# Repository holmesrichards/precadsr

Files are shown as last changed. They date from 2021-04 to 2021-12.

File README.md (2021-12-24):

# Kassutronics Precision ADSR with retriggering and looping modifications

This is an ADSR envelope generator synth module. Layout and panel are Kosmo format. 

The main part of the design is from [Kassutronics](https://kassu2000.blogspot.com/2015/05/precision-adsr.html), who in turn based it on the YuSynth [ADSR (version 2)](http://yusynth.net/Modular/EN/ADSR/index_new.html), which is similar to René Schmitz's [Fastest Envelope In the West](https://www.schmitzbits.de/adsr.html). The latter two, like some other envelope generators, have the problem that the voltage releases very slowly after reaching about 700 mV, taking several seconds or longer to drop below 100 mV. Kassutronics fixed this by replacing the decay and release diodes with precision rectifiers (op amp with diode in the feedback loop). Another modification was a clever way of combining the LED indicator with the inverted envelope output using a single op amp.

The present design adds the following features:

* Two switch selectable capacitors for slower and faster time scales (restoring a feature of the YuSynth ADSR, though without the two resistors in the attack path).
* Capacitors can be socketed for experimentation, soldered, or socketed at first and soldered later.
* Retriggering input, allowing additional attack/decay peaks on top of the sustain (inspired by but simplified from Benjamin AM's [design](https://electro-music.com/forum/post-372492.html#372492)).
* Looping mode, allowing attack-decay envelopes to repeat as long as a gate is present, or, if nothing is plugged into the gate input, indefinitely. This can be used as a sequence of envelopes or as a kind of odd LFO.

## Current draw
12 mA +12 V, 10 mA -12 V

## Photos

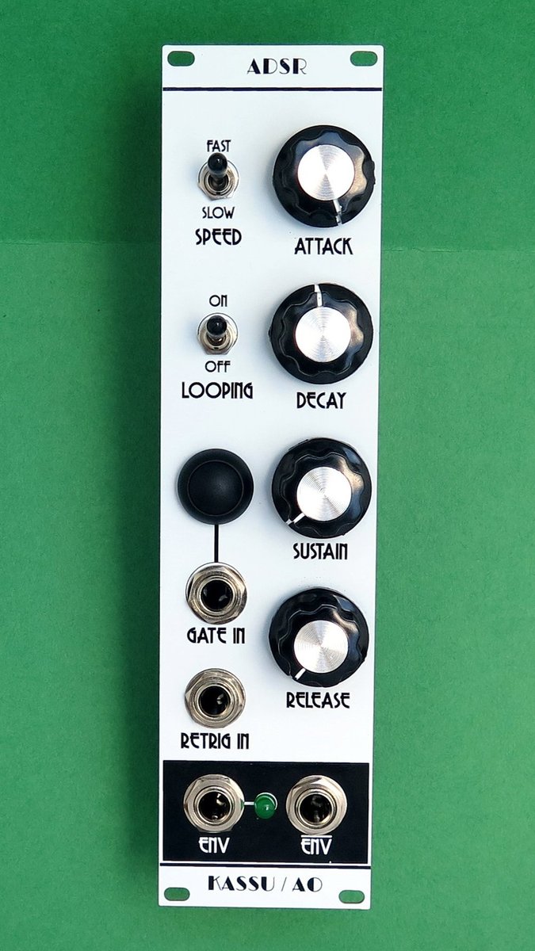
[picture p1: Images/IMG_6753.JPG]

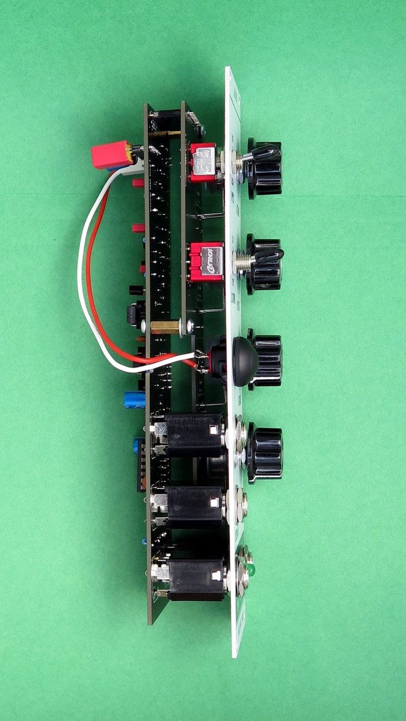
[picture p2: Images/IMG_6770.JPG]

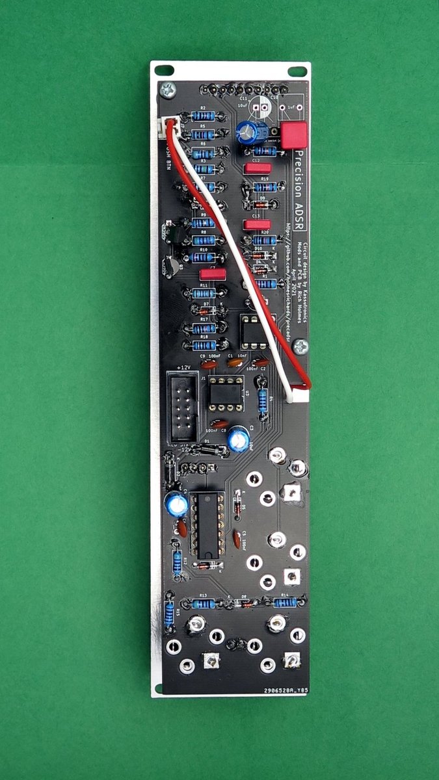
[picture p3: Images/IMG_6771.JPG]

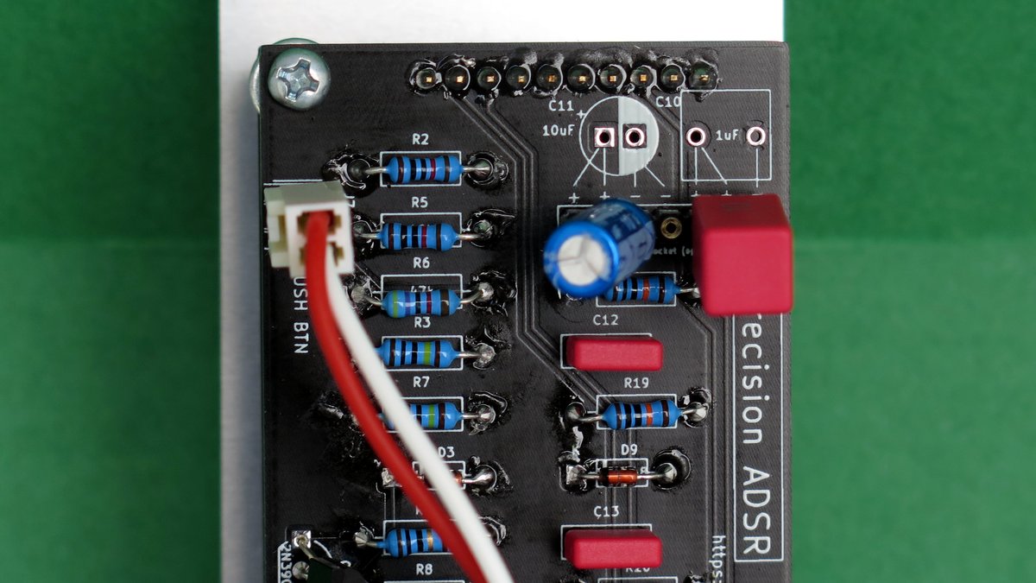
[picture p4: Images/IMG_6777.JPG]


## Documentation:

* [Schematic](Docs/precadsr.pdf)
* PCB layout: [front](Docs/precadsr_layout_front.pdf), [back](Docs/precadsr_layout_back.pdf)
* [BOM](Docs/precadsr_bom.md)
* [Build notes](Docs/build.md)
* [How to use](Docs/use.md)

## GitHub repository

* [https://github.com/holmesrichards/precadsr](https://github.com/holmesrichards/precadsr)

## Submodules

This repo uses submodules aoKicad and Kosmo_panel, which provide needed libaries for KiCad. To clone:

```
git clone git@github.com:holmesrichards/precadsr.git
git submodule init
git submodule update
```

Alternatively do

```
git clone --recurse-submodules git@github.com:holmesrichards/precadsr.git
```

Or if you download the repository as a zip file, you must also click on the "aoKicad" and "Kosmo\_panel" links on the GitHub page (they'll have "@ something" after them) and download them as separate zip files which you can unzip into the aoKicad and Kosmo\_panel directories.

If desired, copy the files from aoKicad and Kosmo\_panel to wherever you prefer (your KiCad user library directory, for instance, if you have one). Then in KiCad, add symbol libraries 

```
aoKicad/ao_symbols
Kosmo_panel/Kosmo
```
and footprint libraries 
```
aoKicad/ao_tht
Kosmo_panel/Kosmo_panel.
```

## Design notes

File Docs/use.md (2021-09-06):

# Using the Precision ADSR with retriggering and looping

## Gated ADSR operation

It's just like pretty much any ADSR envelope generator. Put a gate into the Gate In jack (or generate a gate manually using the push button). The start (rising edge) of the gate will initiate the attack, followed by the decay to the sustain level after maximum amplitude is reached (about 8 V). The end (falling edge) of the gate will initiate the release to 0 V. Attack, Decay, and Release times, and Sustain level, are set using the knobs. The Speed switch allows choosing faster or slower time ranges for the Attack, Decay, and Release times.

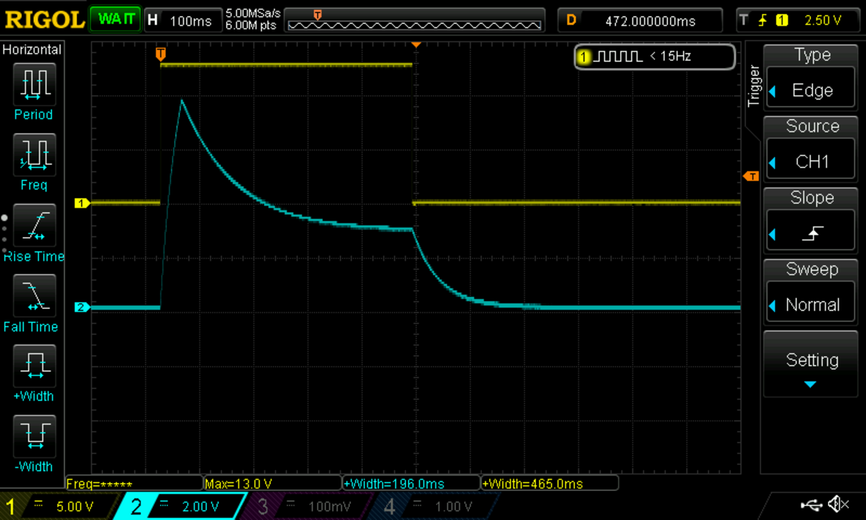
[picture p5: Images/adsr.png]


## Inverted output

Whatever appears on the Env output, its negative will appear on the ~Env output. You can use this, for instance, to duck a VCA level using a gate.

## Retriggering

It can be useful to have a new Attack/Decay for new notes without a release to 0 V before them. To do this send a gate to the Gate In (or push the button) and triggers to Retrig In. As usual the gate will initiate an Attack, Decay, Sustain, and Release. However, pulses on the Retrig In jack during the Decay/Sustain phase will cause new Attacks and Decays to occur.

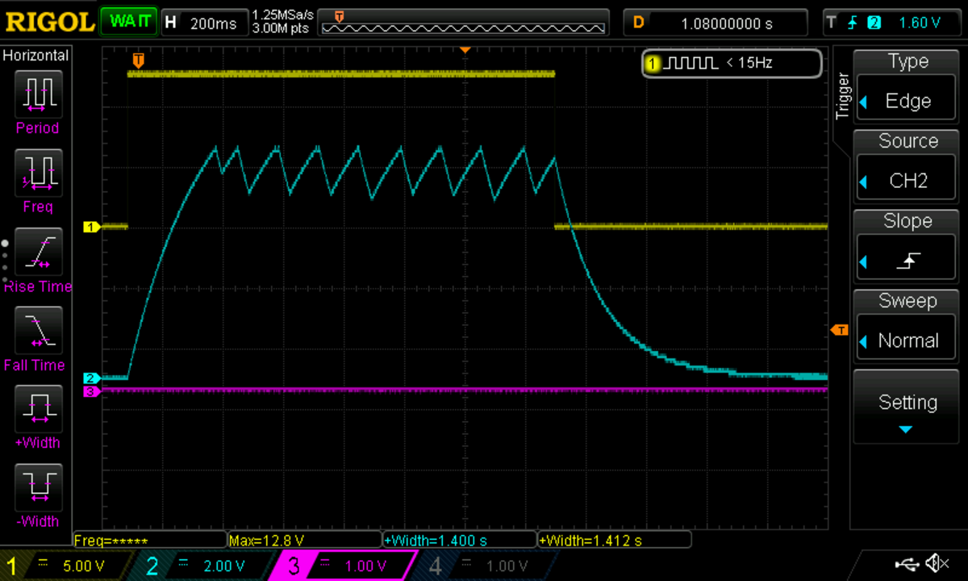
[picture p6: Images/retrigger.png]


## Looping

With the Looping switch in the On position, a gate on the Gate In (or pushing the button) will initiate an Attack and Decay to 0 V. The Sustain level and Release times are ignored. When the output gets close to 0 V it will automatically trigger a new Attack and Decay. The Attacks and Decays will repeat as long as the gate is on. When the gate goes off the looping ends.

If nothing is plugged in on the Gate In jack and Looping is turned on, Attacks and Decays will repeat continuously.

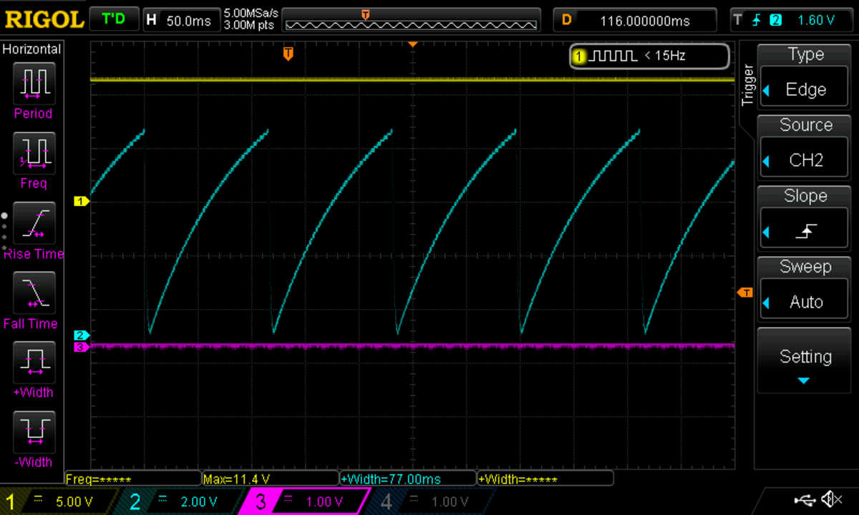
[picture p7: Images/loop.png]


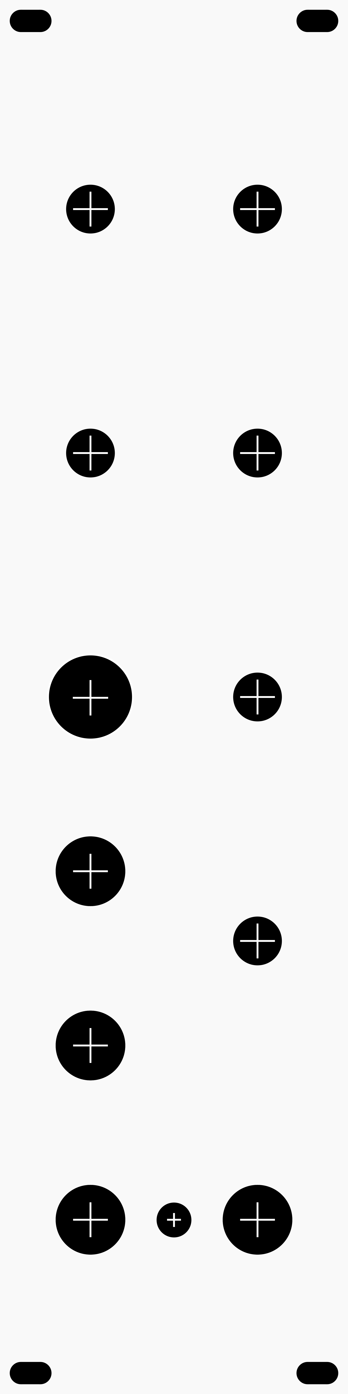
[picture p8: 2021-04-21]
Images/precadsr-panel-holes.png

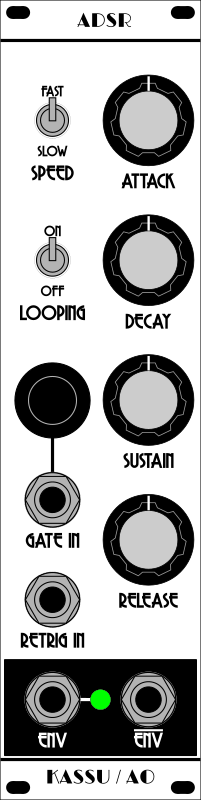
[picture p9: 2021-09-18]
Images/precadsr-panel.png

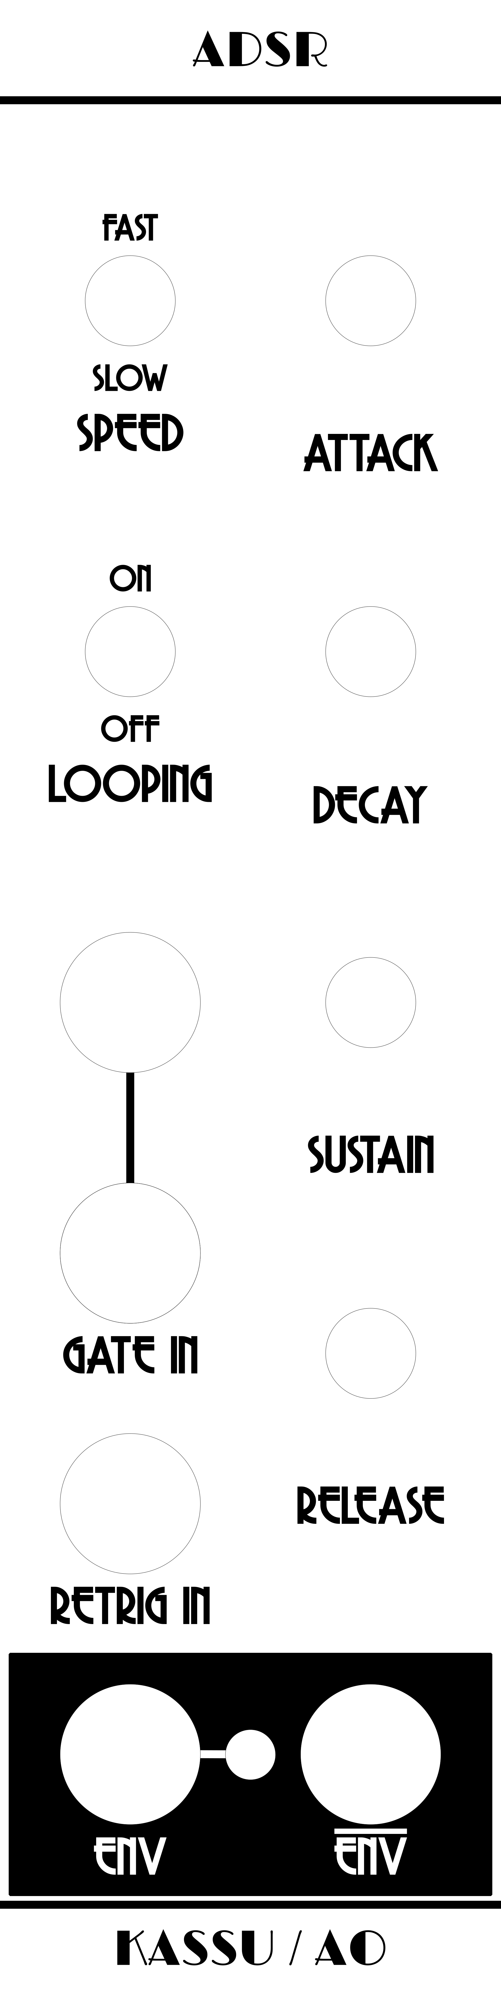
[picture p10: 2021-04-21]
Images/precadsr-panel-art.png

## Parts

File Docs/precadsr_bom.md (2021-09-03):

# precadsr.sch BOM

Sat 28 Aug 2021 07:18:14 PM EDT

Generated from schematic by Eeschema 5.1.10-88a1d61d58~90~ubuntu20.04.1

**Component Count:** 76

| Refs | Qty | Component | Description | Manufacturer | Part | Vendor | SKU |
| ----- | --- | ---- | --- | ---- | ---- | ---- | ---- |
| C1 | 1 | 10nF | Ceramic capacitor |  |  | Tayda | A-962 |
| C2, C5, C6, C8, C9 | 5 | 100nF | Ceramic capacitor |  |  | Tayda | A-553 |
| C3, C4, C11 | 3 | 10uF | Electrolytic capacitor |  |  | Tayda | A-4349 |
| C7, C12 | 2 | 1nF | Film capacitor |  |  | Tayda | A-1531 or A-557 |
| C10 | 1 | 1uF | Film capacitor |  |  | Tayda | A-4755 |
| C13 | 1 | 10nF | Film capacitor |  |  | Tayda | A-559 |
| D1, D2 | 2 | 1N5817 | Schottky Barrier Rectifier Diode, DO-41 |  |  | Tayda | A-159 |
| D3, D4, D5, D6, D7, D8, D9, D10 | 8 | 1N4148 | Standard switching diode, DO-35 |  |  | Tayda | A-157 |
| J1 | 1 | Synth_power_2x5 | Pin header 2.54 mm 2x5 |  |  | Tayda | A-2939 |
| J2 | 1 | AudioJack2_SwitchT | Audio Jack, 2 Poles (Mono / TS), Switched T Pole (Normalling) |  |  | Tayda | A-1121 |
| J3, J4, J5 | 3 | AudioJack2 | Audio Jack, 2 Poles (Mono / TS) |  |  | Tayda | A-1121 |
| J6 | 1 | Conn_01x07 | \*(optional) SIP socket, 2.54 mm, 1x7 |  |  | Tayda | A-1605 |
| J7 | 1 | 2_pin_Molex_header | KK254 Molex header |  |  | Tayda | A-804 |
| J8 | 1 | Conn_01x10 | Pin socket, 2.54 mm, 1x10 |  |  |  |  |
| J9 | 1 | Conn_01x04 | Pin socket, 2.54 mm, 1x4 |  |  |  |  |
| J10 | 1 | Conn_01x10 | Pin header, 2.54 mm, 1x10 |  |  |  |  |
| J11 | 1 | Conn_01x04 | Pin header, 2.54 mm, 1x4 |  |  |  |  |
| J12 | 1 | 2_pin_Molex_connector | KK254 Molex connector |  |  | Tayda | A-826 |
| L1 | 1 | LED | Light emitting diode, 5 mm |  |  |  |  |
| Q1, Q2, Q3 | 3 | 2N3904 | Small Signal NPN Transistor, TO-92 |  |  | Tayda | A-111 |
| R1, R10, R11 | 3 | 22k | Resistor |  |  |  |  |
| R2, R5 | 2 | 10k | Resistor |  |  |  |  |
| R3, R7 | 2 | 1M | Resistor |  |  |  |  |
| R4, R12, R13 | 3 | 4.7k | Resistor |  |  |  |  |
| R6, R8 | 2 | 47k | Resistor |  |  |  |  |
| R9 | 1 | 10R | Resistor |  |  |  |  |
| R14, R15, R18 | 3 | 1k | Resistor |  |  |  |  |
| R16, R17, R19, R20 | 4 | 100k | Resistor |  |  |  |  |
| R21, R22, R23 | 3 | 100R | Resistor |  |  |  |  |
| R24, R26, R28 | 3 | A1M | \*\*Potentiometer, 9 mm vertical board mount OR: |  |  | Tayda | A-1672 |
| R25, R27, R29 | 3 | A1M | \*\*Potentiometer, 16 mm vertical board mount |  | | Tayda | A-1157 or A-2425 |
| R30 | 1 | B10k | \*\*Potentiometer, 9 mm vertical board mount OR: |  |  | Tayda | A-1847 |
| R31 | 1 | B10k | \*\*Potentiometer, 16 mm vertical board mount |  |  | Tayda | A-1624 or A-2969 |
| S1 | 1 | SW_3PDT_x3 | 3PDT miniature toggle switch ON-ON |  |  | Tayda | A-1955 |
| S2 | 1 | SW_SPDT | SPDT miniature toggle switch ON-ON |  |  | Tayda | A-3186 |
| S3 | 1 | SW_Push | Push button switch OFF-(ON) | Dailywell | PAS6B3M1CESA3-5 or PAS6B3M1CESA2-5 | Tayda | A-3486 or A-3487\*\*\* |
| U1 | 1 | ICM7555xP | CMOS General Purpose Timer, 555 compatible, PDIP-8 |  |  |  |  |
| U2 | 1 | TL074 | Quad operational amplifier, DIP-14 |  |  | Tayda | A-1138 |
| U3 | 1 | TL071 | Operational amplifier, DIP-8 |  |  | Tayda | A-1135 |
| | 2 | | 8 pin DIP socket | | | Tayda | A-001 |
| | 1 | | 14 pin DIP socket | | | Tayda | A-004 |
| | 4 | | Knobs | | | |
| | | | Screws, nuts, and spacers (see [build notes](build.md))
| | 1 | Conn_01x02 | SIP socket, 2.54 mm, 1x2 (see [build notes](build.md)) |  |  | Tayda | A-1605 |

\* Fit SIP socket only if you want to socket the timing capacitors.
\*\* Use only four (4) potentiometers, either 9 mm or 16 mm vertical board mount. Only 16 mm have been tested and there could be mechanical difficulties using 9 mm. See [build notes](build.md).
\*\*\* A-3488 looks similar but is normally closed rather than normally open and will not work. Ask me how I know this. And by "ask me" I mean "shut up".

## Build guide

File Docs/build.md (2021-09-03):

# Precision ADSR build notes

The build is pretty straightforward except for mechanical assembly, and two other things:

## Erratum

C13 is marked on the first run PCBs as 1 nF. It should be 10 nF.

## Timing capacitors

C10 and C11 are the capacitors that determine the envelope shape in conjunction with the four pots. The "Speed" switch selects whether C10 ("fast") or C11 ("slow") is used. 1 µF for C10 and 10 µF for C11 is suggested but you can try other values, smaller ones for faster timings and larger ones for slower.

If you want to experiment, you can. J6 is an optional SIP socket (you could use a pin socket, but a SIP socket works better) for socketing the capacitors. There are 7 positions. As indicated by the lines on the silkscreen graphtics, the C11 + leg (if polarized) can go in either of the leftmost two positions, the C11 - leg in either of the next two, the C10 + leg in either of the next two, and the C10 - leg in the last one. This accommodates various possibilities for cap lead spacing. When and if you decide on a pair of capacitors you can solder them into the C10 and C11 footprints above the SIP socket.

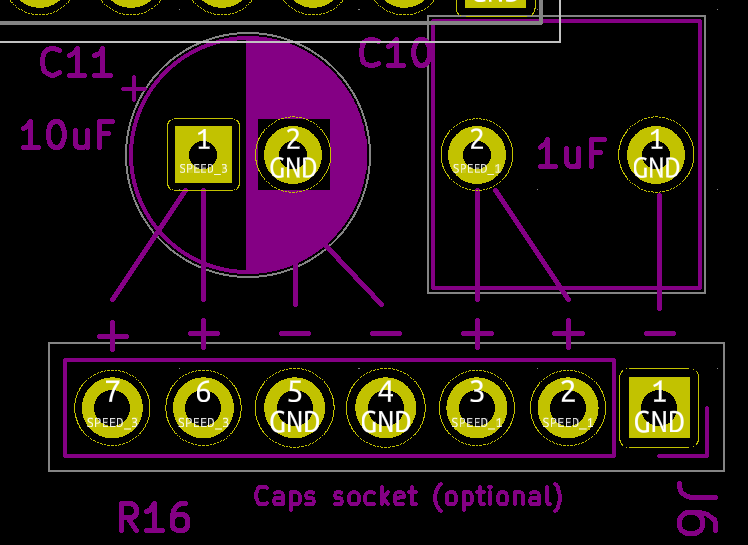
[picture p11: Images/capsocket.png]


I tried one sample each of aluminum electrolytic and tantalum at 1 µF and 10 µF, as well as a PET film at 1 µF. Attack was set fairly fast, sustain at 100%, release as fast as possible. Interestingly, the tantalum was better (less sag over a 2.5 second sustain) than the aluminum at 1 µF, but at 10 µF the aluminum looked better while the tantalum was horrible: 

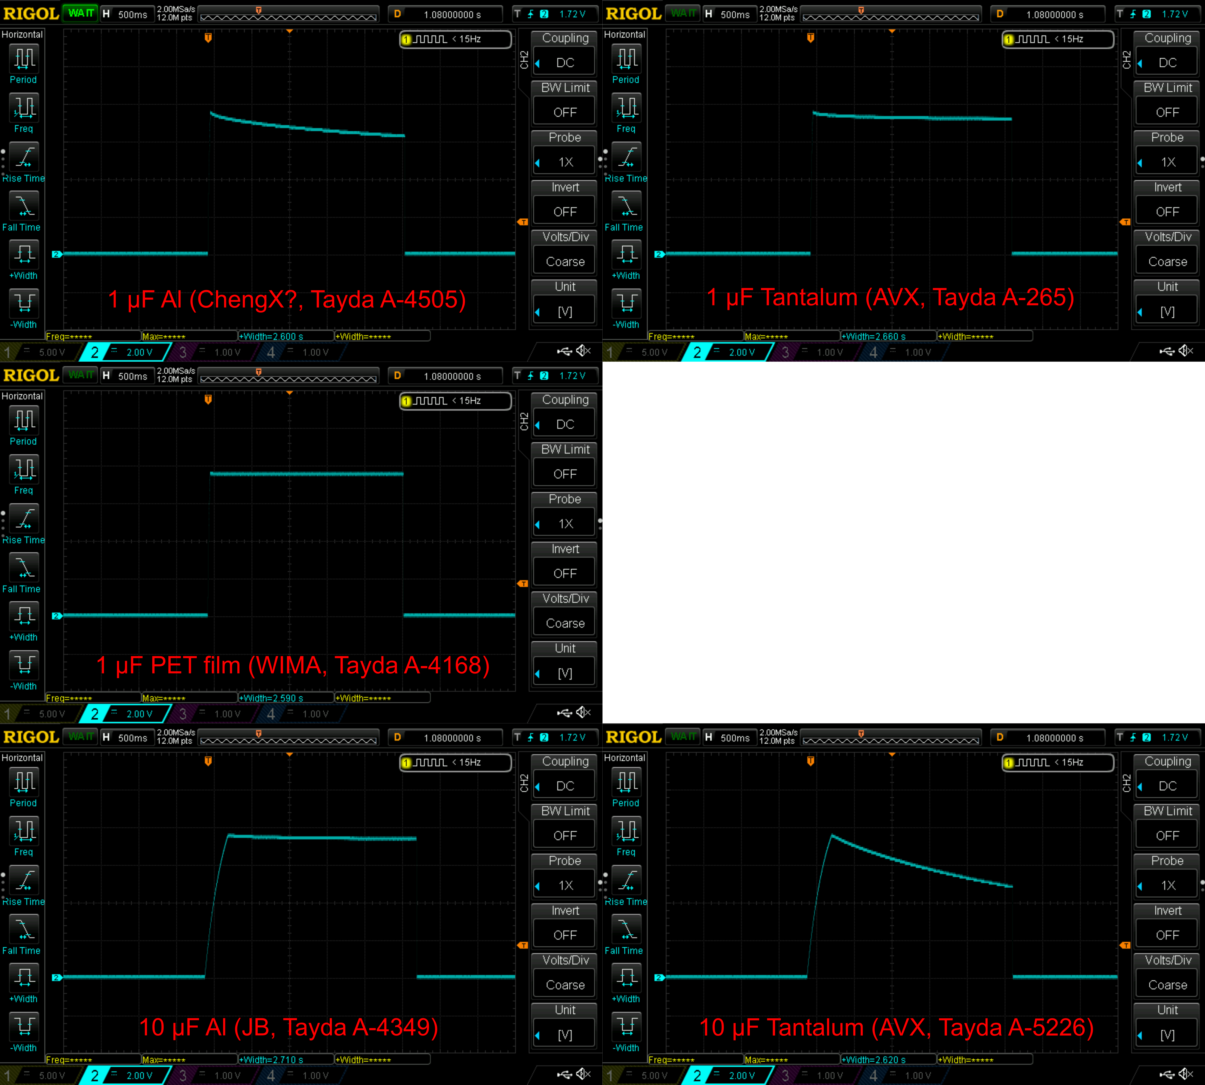
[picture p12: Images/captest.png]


I was sufficiently shocked by the 10 µF tanty to try two more (same type, from the same order). One looked about the same, the other was worse. 

The 1 µF film ruled, however; it was just about perfectly flat across the full sustain. Unfortunately 10 µF film caps are large and expensive, and ten 1 µF film caps in parallel would require an auxiliary board nearly as large as the main one. So my current preference is a 1 µF film and a 10 µF aluminum. Of course a sample of one of each type is not a lot to go on.

## Mechanical assembly

Regarding the board mounted potentiometers, there are two overlapping footprints provided for each, allowing you to use your choice of 9 mm or 16 mm vertical pots. You can even use a mix of the two, if you want. But see below for possible issues; I have tested only 16 mm.

Putting everything together is a little complicated. At least it is if your 3PDT toggle switch, like mine, is a few mm taller than the SPDT toggle.\* In that case the pots and switches board ("Board B") must sit a few mm further from the front panel than usual.

At least with the components I used, I found:

* The SPDT toggle switch could be used with a nut under the front panel. I adjusted the height of that nut to match the height of the 3PDT switch. I did not use a nut behind the panel on the 3PDT switch.

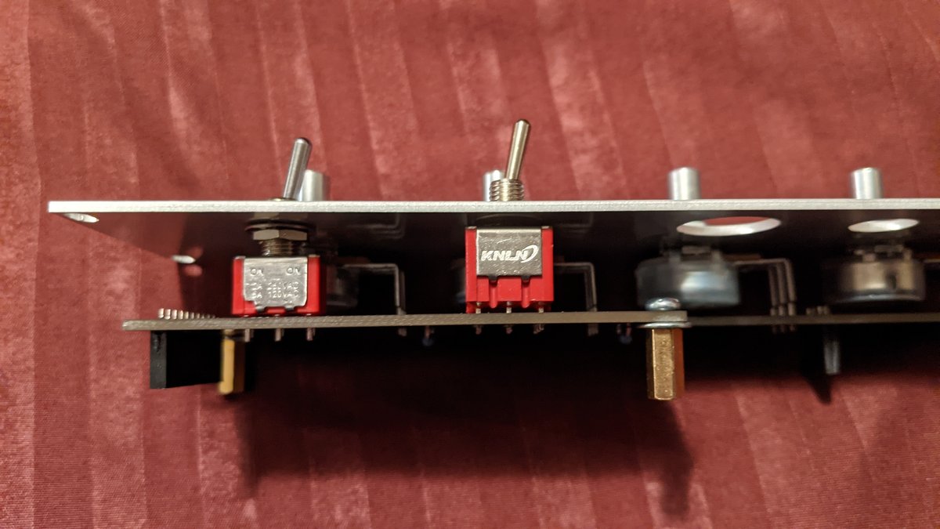
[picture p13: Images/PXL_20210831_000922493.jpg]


* The 16 mm pots had long enough terminals, barely, to poke through the PCB enough for soldering with the pots mounted flush to the back of the front panel. This leaves a gap between the pots and the PCB.

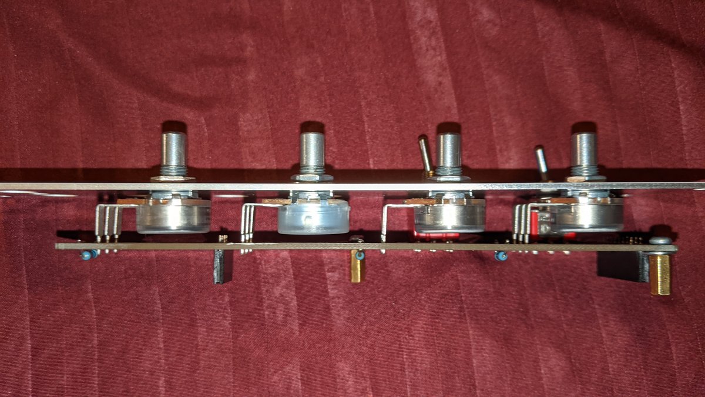
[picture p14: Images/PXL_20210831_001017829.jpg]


If you use 9 mm pots, you're on your own!

* The jacks, like the SPDT switch, needed a nut behind the front panel. Tightening it down all the way to the jack body made the height about right. 

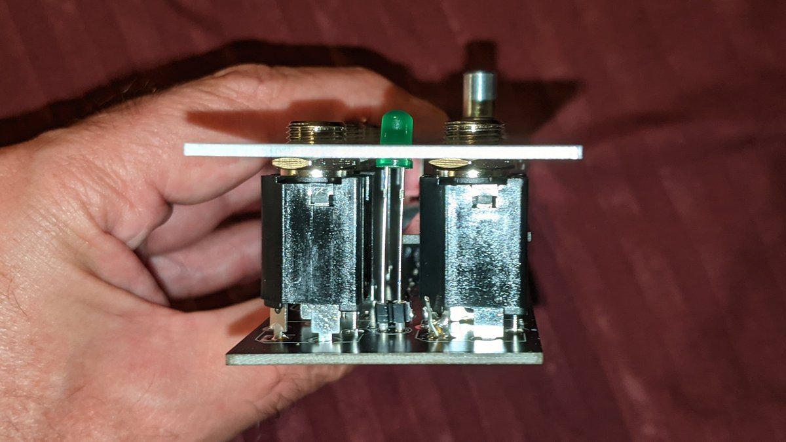
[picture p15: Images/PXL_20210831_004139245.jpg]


It's easier to tell in real life than in the photo that the front panel and PCBs are not quite parallel, but they're close.

* In the above photo you can also see my solution to getting the LED legs to reach. I mounted a 2-position SIP socket in the LED footprint and socketed the LED.

## Assembly order

I suggest the following procedure for assembly. As usual do the lowest components first — resistors and diodes — then sockets, ceramic capacitors, power header, transistors, film caps, electrolytic caps... something like that.

To do the pin headers and sockets, first attach spacers on the non component side of Board B. (I used 10 mm spacers plus a washer.) Next mate the headers and sockets. Place the header pins in the Board A footprints. Make sure to put them on the non component side. Don't solder anything. Put Board B on, pot and switch footprints side up, with the socket pins going into their footprints. Don't solder anything. Screw the other ends of the spacers to Board A. Now solder the pin headers and sockets in place.

To mount the potentiometers and switches, separate the two boards again. Place the pots and switches on their footprints on Board B. Don't solder anything. Adjust the nut height on the SPDT switch. Place the front panel over the pots and switches so it is flush with the top of the 3PDT switch and more or less parallel to the board. The SPDT nut should be against the back of the panel. Add washers and nuts, finger tight, to all pots and switches. Verify the pot terminals get through the PCB. Now solder the pots and switches.

To mount the jacks and LED, place the jacks on their footprints on Board A and the LED in the SIP socket. Don't solder anything. Adjust the nut heights on the jacks and verify the height of the LED, trimming its legs as needed. Mate Board A to Board B and the front panel with the jacks and LED going through their panel holes; the LED and the nuts on the jacks should be against the back of the panel. Add washers and nuts, finger tight, to all jacks. Now solder the jacks.

The push button switch goes into the hole on the front panel and then stranded wires run from its terminals to a 2-pin Molex connector. Wires should be long enough to reach the Molex header on Board A. They can be routed through the notch on the edge of Board A. Make sure the switch you use is normally open (OFF-(ON)). Tayda sells a similar looking switch which is normally closed (ON-(OFF)). That won't work.

----

\* The Dailywell 3PDT and SPDT toggle switches available from Tayda, per their datasheet, appear to differ in height by 3.16 mm. (8.89 mm vs (10.54+1.52) mm if I'm reading it right.)

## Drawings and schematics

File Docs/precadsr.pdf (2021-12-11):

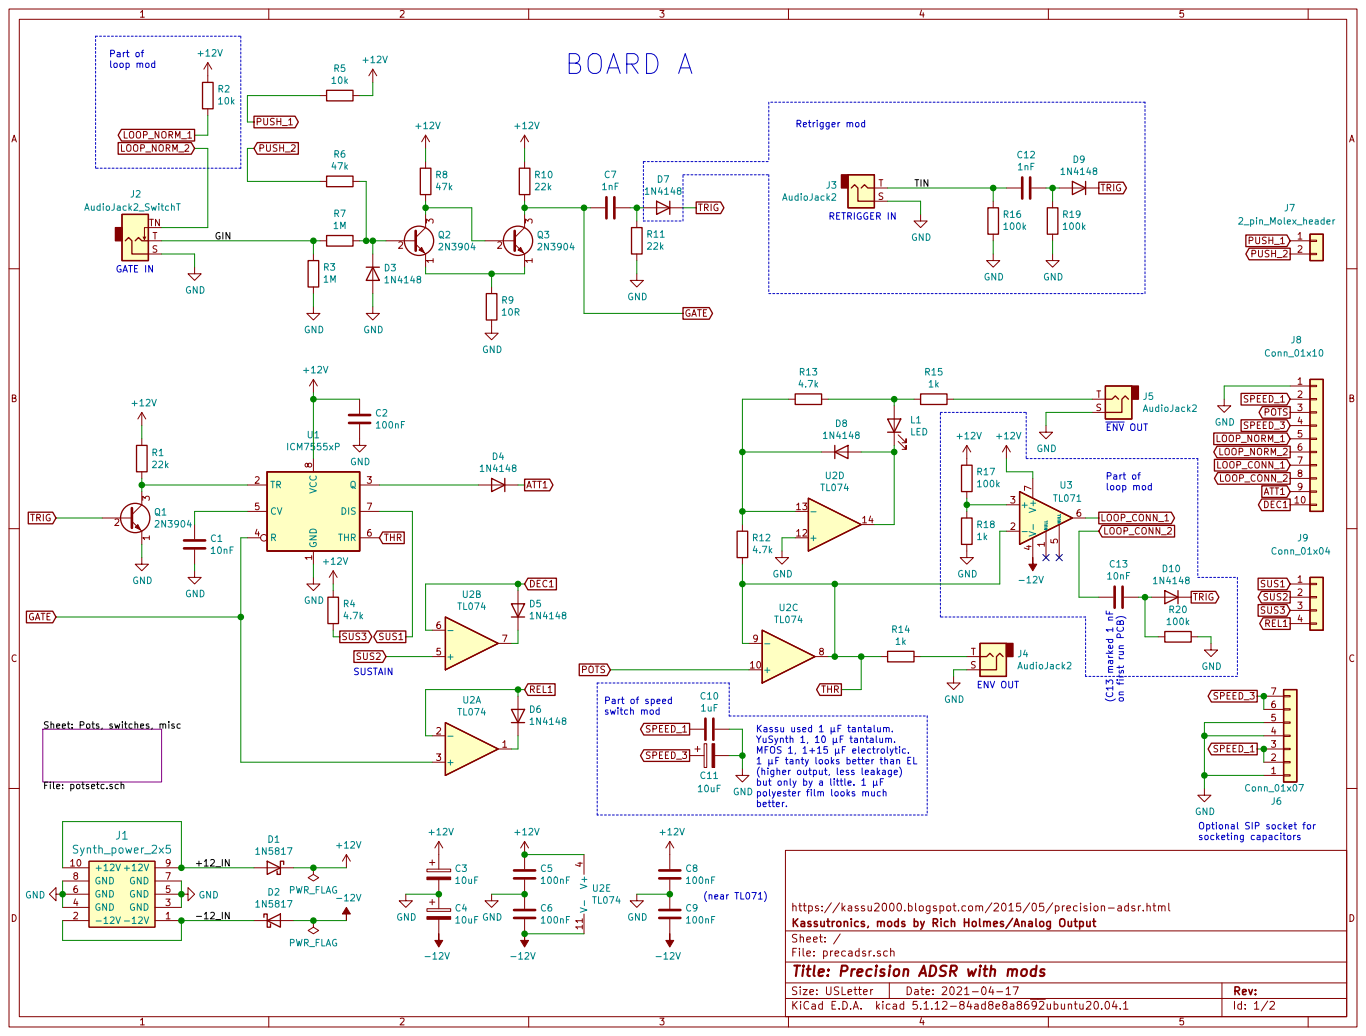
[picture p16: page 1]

socketing capacitors Part of

Part of speed switch mod GATE IN

https://kassu2000.blogspot.com/2015/05/precision-adsr.html Sheet: Pots, switches, misc File: potsetc.sch

Kassu used 1 µF tantalum.
YuSynth 1, 10 µF tantalum.
MFOS 1, 1+15 µF electrolytic.
1 µF tanty looks better than EL
(higher output, less leakage)
but only by a little. 1 µF

File: precadsr.sch Sheet: / Kassutronics, mods by Rich Holmes/Analog Output

Id: 1/2 Title: Precision ADSR with mods

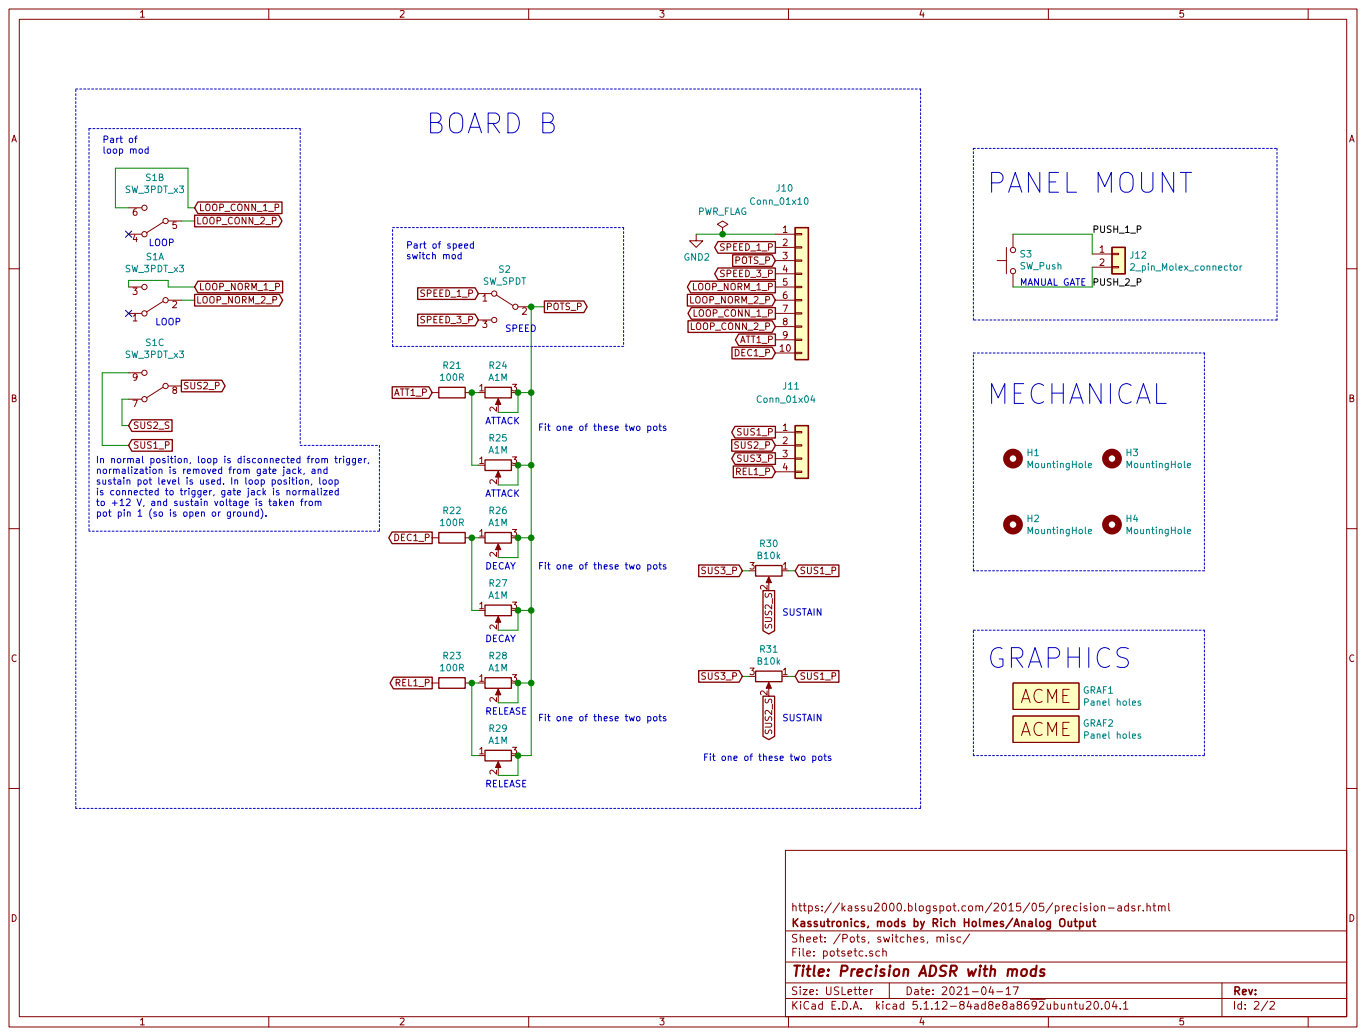
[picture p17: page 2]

Part of speed switch mod

In normal position, loop is disconnected from trigger,
normalization is removed from gate jack, and
sustain pot level is used. In loop position, loop
is connected to trigger, gate jack is normalized
to +12 V, and sustain voltage is taken from
pot pin 1 (so is open or ground).

Fit one of these two pots

Fit one of these two pots SUSTAIN

https://kassu2000.blogspot.com/2015/05/precision-adsr.html
Kassutronics, mods by Rich Holmes/Analog Output
Sheet: /Pots, switches, misc/
File: potsetc.sch
Id: 2/2 Title: Precision ADSR with mods

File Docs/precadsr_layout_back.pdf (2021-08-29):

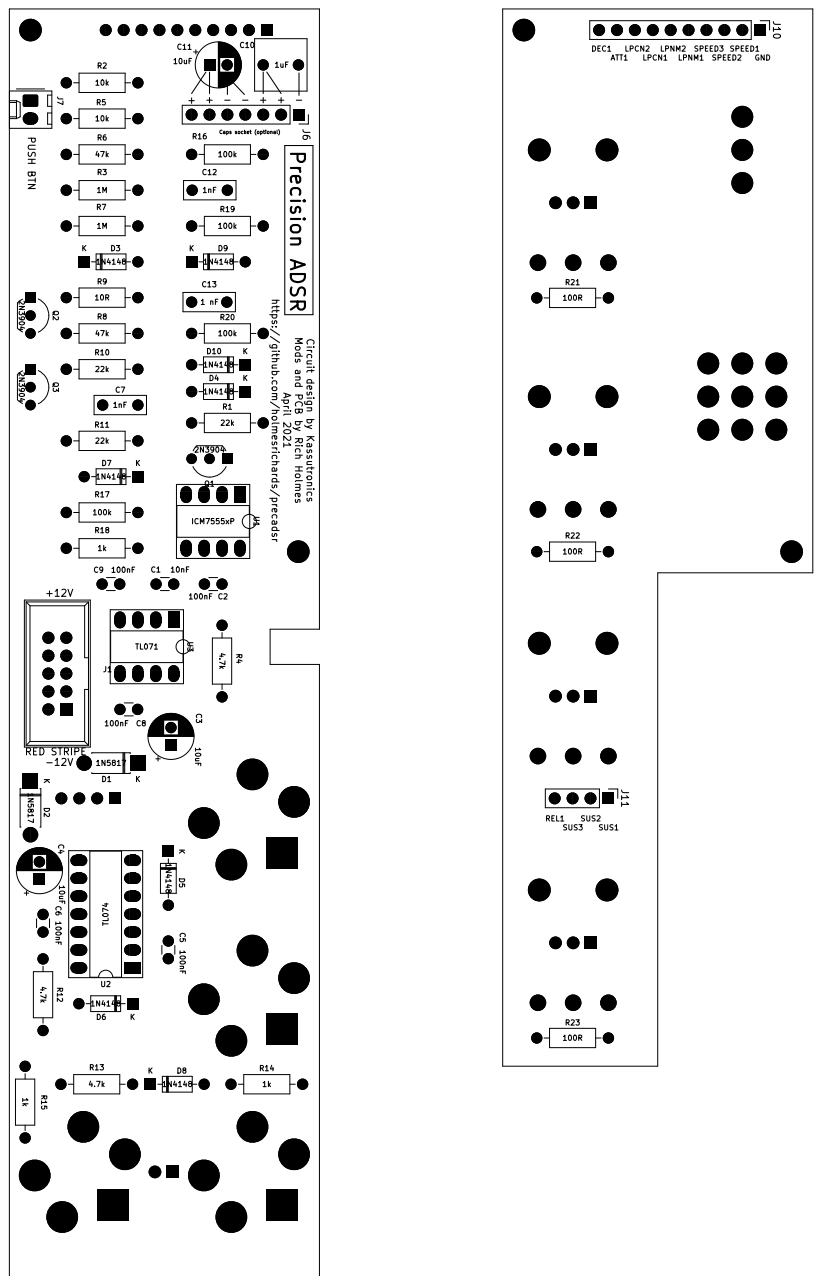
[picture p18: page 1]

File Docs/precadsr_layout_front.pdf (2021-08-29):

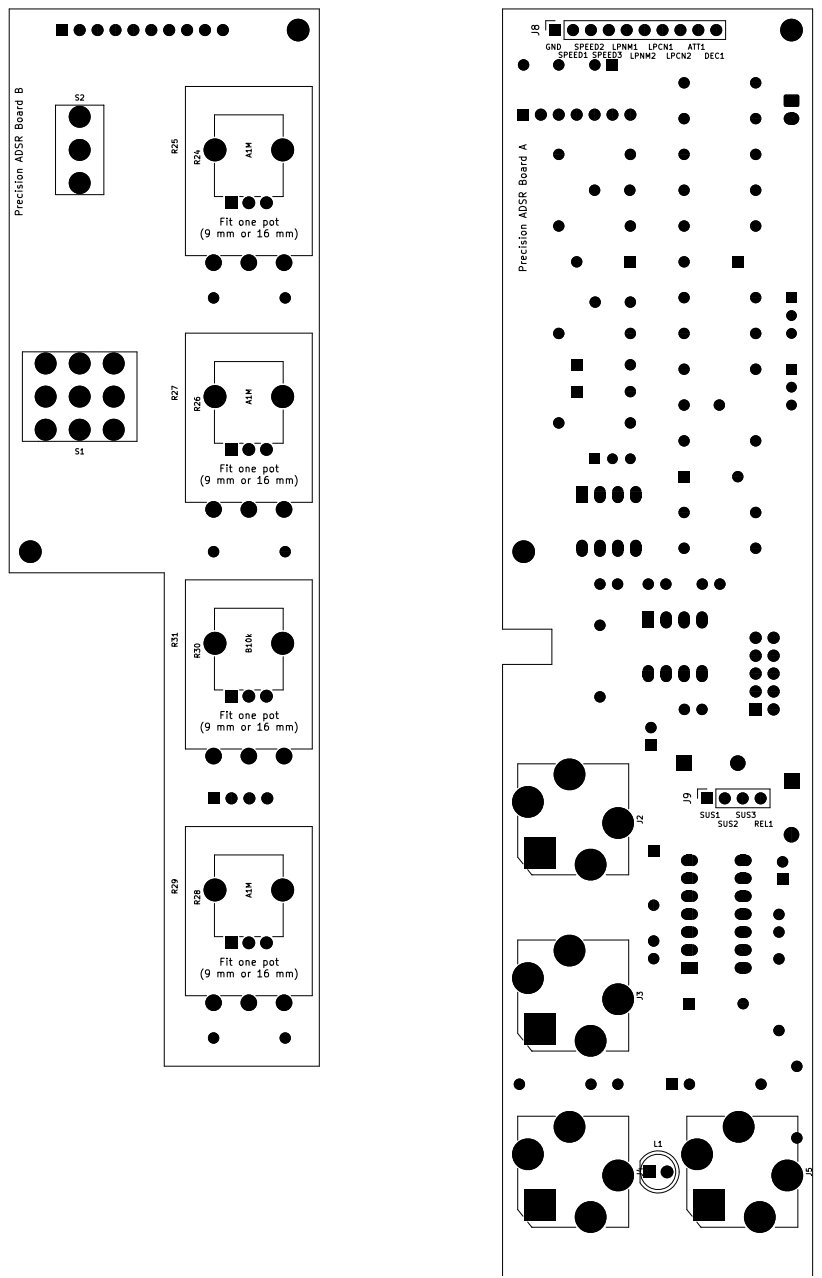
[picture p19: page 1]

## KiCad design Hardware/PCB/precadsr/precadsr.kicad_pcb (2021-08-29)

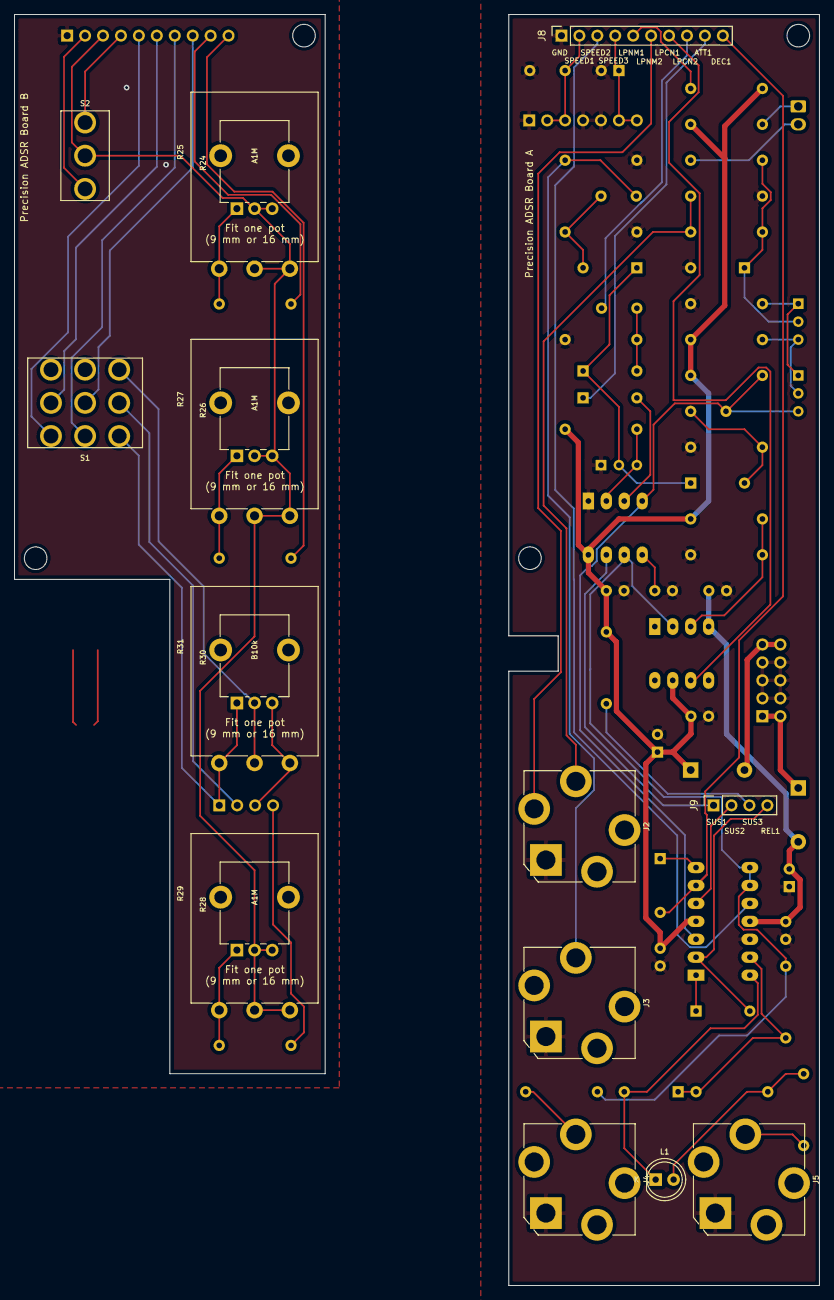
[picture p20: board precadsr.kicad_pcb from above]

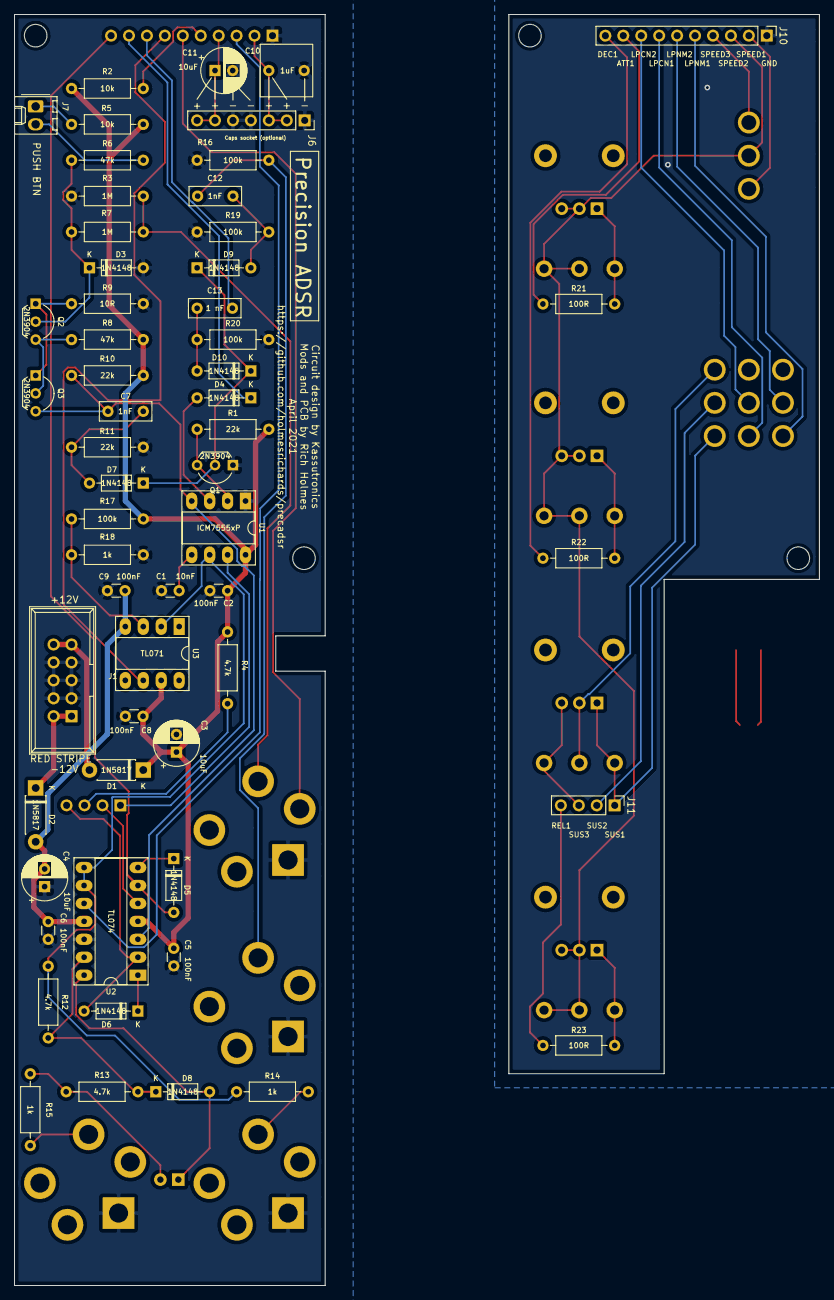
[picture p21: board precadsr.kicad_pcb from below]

Board: 2 copper layers, 114.0 x 180.0 mm, 80 parts (57 on the bottom side), 59 nets.

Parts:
C1: 10nF; C_Disc_D3.0mm_W1.6mm_P2.50mm
C2, C5, C6, C8, C9: 100nF; C_Disc_D3.0mm_W1.6mm_P2.50mm
C3, C4, C11: 10uF; CP_Radial_D6.3mm_P2.50mm
C7, C12: 1nF; C_Rect_L7.2mm_W2.5mm_P5.00mm_FKS2_FKP2_MKS2_MKP2
C10: 1uF; C_Rect_L7.2mm_W7.2mm_P5.00mm_FKS2_FKP2_MKS2_MKP2
C13: 1 nF; C_Rect_L7.2mm_W2.5mm_P5.00mm_FKS2_FKP2_MKS2_MKP2
D1, D2: 1N5817; D_DO-41_SOD81_P7.62mm_Horizontal
D3, D4, D5, D6, D7, D8, D9, D10: 1N4148; D_DO-35_SOD27_P7.62mm_Horizontal
GRAF1, GRAF2: Panel holes; precadsr-panel-holes
H1, H2, H3, H4: MountingHole; MountingHole_3.2mm_M3
J1: Synth_power_2x5; Power_Header
J2: AudioJack2_SwitchT; Jack_6.35mm_PJ_629HAN
J3, J4, J5: AudioJack2; Jack_6.35mm_PJ_629HAN
J6: Conn_01x07; PinSocket_1x07_P2.54mm_Vertical
J7: 2_pin_Molex_header; Molex_KK-254_AE-6410-02A_1x02_P2.54mm_Vertical
J8: Conn_01x10; PinSocket_1x10_P2.54mm_Vertical
J9: Conn_01x04; PinSocket_1x04_P2.54mm_Vertical
J10: Conn_01x10; PinHeader_1x10_P2.54mm_Vertical
J11: Conn_01x04; PinHeader_1x04_P2.54mm_Vertical
L1: LED; LED_D5.0mm
Q1, Q2, Q3: 2N3904; TO-92_Inline_Wide
R1, R10, R11: 22k; R_Axial_DIN0207_L6.3mm_D2.5mm_P10.16mm_Horizontal
R2, R5: 10k; R_Axial_DIN0207_L6.3mm_D2.5mm_P10.16mm_Horizontal
R3, R7: 1M; R_Axial_DIN0207_L6.3mm_D2.5mm_P10.16mm_Horizontal
R4, R12, R13: 4.7k; R_Axial_DIN0207_L6.3mm_D2.5mm_P10.16mm_Horizontal
R6, R8: 47k; R_Axial_DIN0207_L6.3mm_D2.5mm_P10.16mm_Horizontal
R9: 10R; R_Axial_DIN0207_L6.3mm_D2.5mm_P10.16mm_Horizontal
R14, R15, R18: 1k; R_Axial_DIN0207_L6.3mm_D2.5mm_P10.16mm_Horizontal
R16, R17, R19, R20: 100k; R_Axial_DIN0207_L6.3mm_D2.5mm_P10.16mm_Horizontal
R21, R22, R23: 100R; R_Axial_DIN0207_L6.3mm_D2.5mm_P10.16mm_Horizontal
R24, R26, R28: A1M; Potentiometer_Alpha_RD901F-40-00D_Single_Vertical_CircularH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
R25, R27, R29: A1M; Potentiometer_Alpha_16mm_Single_Vertical
R30: B10k; Potentiometer_Alpha_RD901F-40-00D_Single_Vertical_CircularH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
R31: B10k; Potentiometer_Alpha_16mm_Single_Vertical
S1: SW_3PDT_x3; 3PDT-toggle-switch-1M-seriesx
S2: SW_SPDT; SPDT-toggle-switch-1M-series
U1: ICM7555xP; DIP-8_W7.62mm_Socket_LongPads
U2: TL074; DIP-14_W7.62mm_Socket_LongPads
U3: TL071; DIP-8_W7.62mm_Socket_LongPads

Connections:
+12V: C2.1, C3.1, C5.1, C8.1, D1.1, R1.1, R2.2, R4.2, R5.1, R8.2, R10.2, R17.2, U1.8, U2.4, U3.7
-12V: C4.2, C6.2, C9.2, D2.2, U2.11, U3.4
/+12_IN: D1.2, J1.9, J1.10
/-12_IN: D2.1, J1.1, J1.2
/GIN: J2.T, R3.2, R7.2
/TIN: C12.2, J3.T, R16.2
ATT1: D4.1, J8.9
ATT1_P: J10.9, R21.2
DEC1: D5.2, J8.10, U2.6
DEC1_P: J10.10, R22.2
GATE: C7.2, Q3.3, R10.1, U1.4, U2.3
GND: C1.2, C2.2, C3.2, C4.1, C5.2, C6.1, C8.2, C9.1, C10.1, C11.2, D3.2, J1.3, J1.4, J1.5, J1.6, J1.7, J1.8, J2.S, J3.S, J4.S, J5.S, J6.1, J6.4, J6.5, J8.1, Q1.1, R3.1, R9.1, R11.1, R16.1, R18.1, R19.1, R20.1, U1.1, U2.12
LOOP_CONN_1: J8.7, U3.6
LOOP_CONN_1_P: J10.7, S1.6
LOOP_CONN_2: C13.2, J8.8
LOOP_CONN_2_P: J10.8, S1.5
LOOP_NORM_1: J8.5, R2.1
LOOP_NORM_1_P: J10.5, S1.3
LOOP_NORM_2: J2.TN, J8.6
LOOP_NORM_2_P: J10.6, S1.2
unnamed: C1.1, U1.5
unnamed: C7.1, D7.2, R11.2
unnamed: C12.1, D9.2, R19.2
unnamed: C13.1, D10.2, R20.2
unnamed: D3.1, Q2.2, R6.1, R7.1
unnamed: D4.2, U1.3
unnamed: D5.1, U2.7
unnamed: D6.1, U2.1
unnamed: D8.1, R12.2, R13.2, U2.13
unnamed: D8.2, L1.1, U2.14
unnamed: J4.T, R14.1
unnamed: J5.T, R15.1
unnamed: L1.2, R13.1, R15.2
unnamed: Q1.3, R1.2, U1.2
unnamed: Q2.1, Q3.1, R9.2
unnamed: Q2.3, Q3.2, R8.1
unnamed: R17.1, R18.2, U3.3
unnamed: R21.1, R24.1, R25.1
unnamed: R22.1, R26.1, R27.1
unnamed: R23.1, R28.1, R29.1
POTS: J8.3, U2.10
POTS_P: J10.3, R24.2, R24.3, R25.2, R25.3, R26.2, R26.3, R27.2, R27.3, R28.2, R28.3, R29.2, R29.3, S2.2
PUSH_1: J7.1, R5.2
PUSH_2: J7.2, R6.2
REL1: D6.2, J9.4, U2.2
REL1_P: J11.4, R23.2
SPEED_1: C10.2, J6.2, J6.3, J8.2
SPEED_1_P: J10.2, S2.1
SPEED_3: C11.1, J6.6, J6.7, J8.4
SPEED_3_P: J10.4, S2.3
SUS1: J9.1, U1.7
SUS1_P: J11.1, R30.1, R31.1, S1.9
SUS2: J9.2, U2.5
SUS2_P: J11.2, S1.8
SUS2_S: R30.2, R31.2, S1.7
SUS3: J9.3, R4.1
SUS3_P: J11.3, R30.3, R31.3
THR: R12.1, R14.2, U1.6, U2.8, U2.9, U3.2
TRIG: D7.1, D9.1, D10.1, Q1.2

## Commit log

2021-04-21 Initial version
    [potsetc.sch, precadsr-panel.kicad_pcb, precadsr-panel.sch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]
2021-04-28 Various tweaks
    [potsetc.sch, precadsr.kicad_pcb, precadsr.sch]
2021-04-30 Add comments and graphics symbols to schematics
    [potsetc.sch, precadsr.kicad_pcb, precadsr.sch]
2021-05-10 Optional capacitor socket
    [potsetc.sch, precadsr.kicad_pcb, precadsr.sch]
2021-05-21 Change op amp, dims to user drawings
    [potsetc.sch, precadsr.kicad_pcb, precadsr.sch]
2021-07-29 Footprints, PCB update
    [precadsr.kicad_pcb]
2021-08-07 Final tweaks before fabbing; Kosmo_panel lib update
    [potsetc.sch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]
2021-08-12 github url
    [precadsr-B_Cu.gbr, precadsr-B_Mask.gbr, precadsr-B_Paste.gbr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]
2021-08-12 KiCad lib tables
2021-08-12 schematics tweaks
    [precadsr.sch]
2021-08-19 Submodules, improved NPTH
    [precadsr_panel_al.kicad_pcb]
2021-08-19 NPTH new version
    [precadsr_panel_al.kicad_pcb, precadsr_panel_al.sch]
2021-08-21 rm al panel
    [precadsr_panel_al.kicad_pcb, precadsr_panel_al.sch]
2021-08-29 Documentation, some cosmetic sh/PCB updates
    [precadsr.kicad_pcb, precadsr.sch]
2021-09-03 Change C13 to 10 nF
    [precadsr.sch]
2021-09-18 Button color, image location
2021-12-11 Extend trigger mod block to include diode
    [precadsr.sch]
2021-12-24 Current draw
